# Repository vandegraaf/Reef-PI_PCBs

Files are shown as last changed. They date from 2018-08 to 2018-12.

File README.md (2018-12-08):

# Reef-PI_PCBs
Contains schematics and PCB file for use with open source Reef-PI software

2 boards are presently uploaded:
HAT (interface to Raspberry 2 or 3) with following functions:
* Can drive up to 16 external relais modules
* Can drive up to 2 12V dosing pumps
* Can use up to 2 optical ATO (water) sensors
* Can drive multiple DS18B20 temperature sensors
* Can connect to external I2C boards (not yet tested)
It requires an external 12V power supply to operate the dosing pumps
This board has been tested (except I2C, but should be ok). No changes were made to the schematics, but some improvements to power and dosing connections have been made to the PCB
The HAT documentation contains all information of which connectors and related GPIO signals to use

New PWM module added
New Reef-PI_PWM v1.0 PCB files added (no documentation yet). These files have some minor improvements over the tested v0.3, mainly to avoid a potential collission with the DS18B20 connector on the Reef-PI_HAT. No changes have been made to the schematics between v0.3 and v1.0 of the PCB.
This Reef-PI_PWM module fits on top of the Reef-PI_HAT but can of course also be connected via wiring. It must be noted that the distance between the 2.5mm PWM output connectors is very small, only very small 2.5mm connectors will fit if all 16 channels are going to be used. The documentation provides a potential candidate.

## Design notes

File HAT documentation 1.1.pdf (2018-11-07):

Rev: 1.1

Page 1 of 12

# Notes to Reef-PI HAT

### Contents

### 1. Main HAT board: | 3

### 2. Schematic: | 4

### 3. Functional overview: | 5

### 4. BOM: | 5

### 5. Connectors: | 7

5.1. 12V input: | 7

### 5.2. External relays interfaces: | 7

### 5.3. Dosing interfaces: | 8

### 5.4. ATO interface: | 9

### 5.5. Temperature sensor interface: | 10

### 5.6. Raspberry PI interface: | 11

### 5.7. I2C interface: | 11

Figure 1: Top HAT board | 3
Figure 2: Bottom HAT board | 3
Figure 3: HAT schematics | 4
Figure 4: Overview HAT functions | 5
Figure 5: Relays interface | 7
Figure 6: Intended external relays board | 8
Figure 7: Dosing interfaces | 8
Figure 8: 4 pin dosing interfaces | 9
Figure 9: Intended optical water sensor | 10
Figure 10: 3 pin DS18B20 interface | 10
Figure 11: Mounting multiple DS18B20 sensors | 10
Figure 12: Intended 3.5mm stereo jack connector | 11
Figure 13: Raspberry GPIO pin overview | 11
Table 1: Revision history | 2
Table 2: Things to do to this document | 2
Table 3: BOM with values and footprints | 6
Table 4: BOM with datasheets | 6
Table 5: BOM with potential suppliers | 7
Table 6: Top 10 connections | 7
Table 7: Bottom 10 connections | 8
Table 8: Overview GPIO ports to control dosing interfaces | 9

Page 2 of 12

Revision | Reason | Date
1.0 | Original release for HAT v1.0 | 13 Aug 2018
1.1 Update table 6 for temperature sensor (tip and ring reversed) for HAT v1.0 | (thanks to Speedstar) Reviewed and updated HAT.csv file (BOM including datasheets, potential supplier and Manufacturing Part Numbers) Added page numbers to this document Added list of items to update to this document Added revision history to this document | 7 Nov 2018

Table 1: Revision history

Planned updates to this document:

| Planned addition or update
a) Add photo’s of complete assembled Reef-PI HAT
b) Add “introduction” paragraph to describe purpose of the Reef-PI HAT
c) Add “assembly instructions” paragraph
d) Update “relays interface” paragraph: | - Which ULN2803 can be left out if only 4 or 8 relays are required - How to connect relays boards with external power (e.g. 12V)
e) Add “debugging” paragraph
f) Add list of potential “updates to the Reef-PI HAT” design
g) Update figure 11 for better description of temperature sensor cabling
Table 2: Things to do to this document

### 1. Main HAT board:

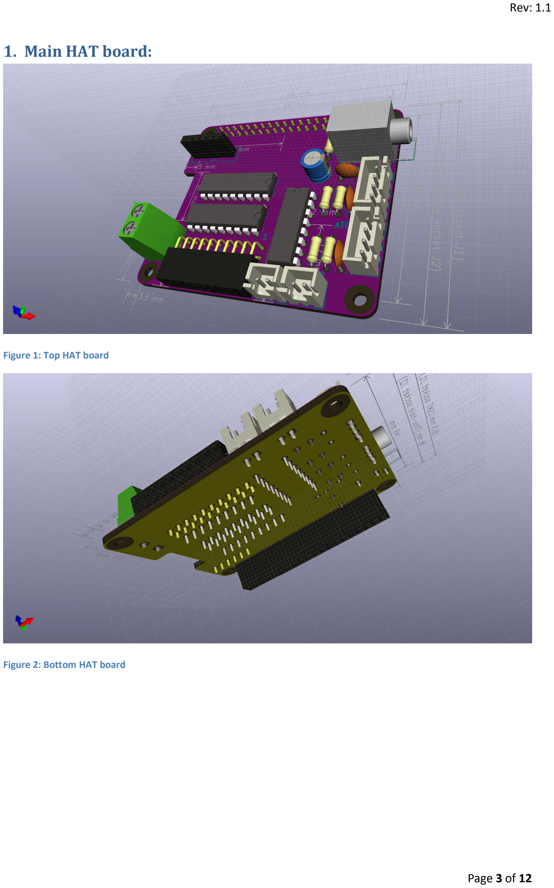
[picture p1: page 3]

Page 3 of 12

Figure 1: Top HAT board

Figure 2: Bottom HAT board

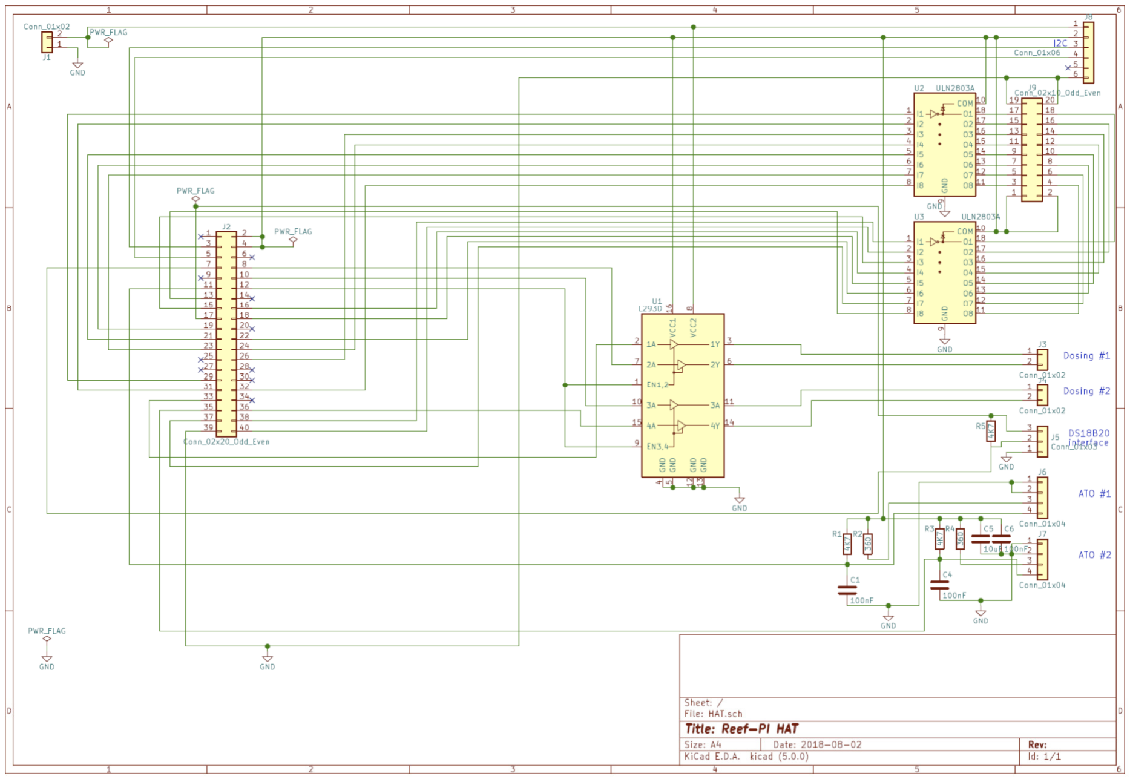
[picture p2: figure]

Page 4 of 12

### 2. Schematic:

Figure 3: HAT schematics

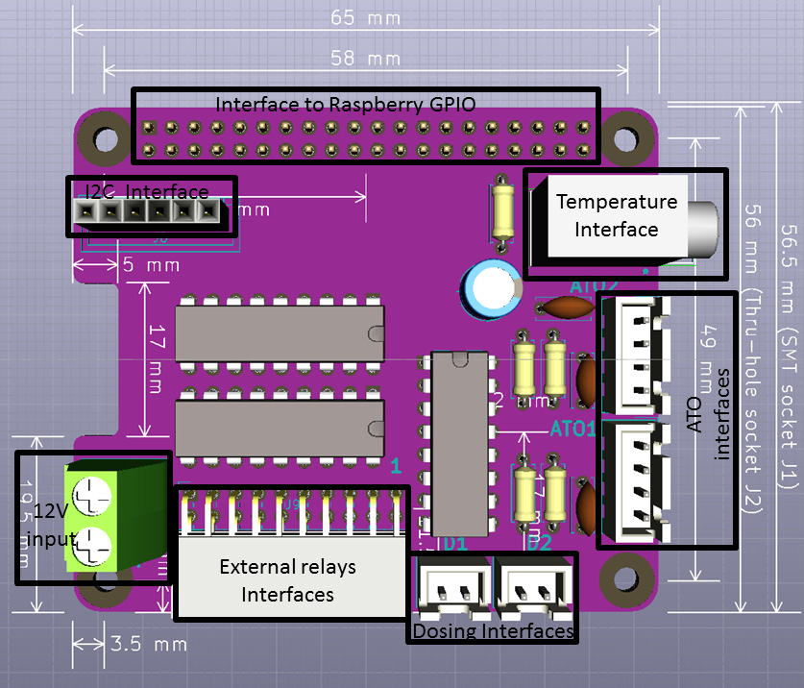
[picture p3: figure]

Page 5 of 12

### 3. Functional overview:

Figure 4: Overview HAT functions

### 4. BOM:

The proposed links are for easy finding, but most components can be found at various Internet sites at better prices such as Aliexpress, Banggood, eBay and Amazon. Purpose of this info is to provide as much as possible of information to find the required components.

The present KiCad files show D1, D2, ATO1 and ATO2 as straight connectors, you may choose to use 90 degree turned connectors for easier access in case additional Reef I2C boards (e.g. PWM module) are going to be added.

Page 6 of 12

Table 3: BOM with values and footprints

Table 4: BOM with datasheets

Title | Reef-PI HAT
Revision | 1
Date | 8/2/2018
Generated | 11/7/2018 8:25
Company
Comment 1
Comment 2
Comment 3
Comment 4
Total Parts | 21
Total Unique Parts 13
Ref | Qty | Value | Footprint
C1 C4 C6 | 3 | 100nF | Capacitors_THT:C_Disc_D6.0mm_W2.5mm_P5.00mm
C5 | 1 | 10uF | Capacitors_THT:CP_Radial_D6.3mm_P2.50mm
J1 | 1 | Conn_01x02 | Pin_Headers:Pin_Header_Straight_1x02_Pitch2.54mm
J2 | 1 | Conn_02x20_Odd_Even | Pin_Headers:Pin_Header_Straight_2x20_Pitch2.54mm
J3 J4 | 2 | Conn_01x02 | Pin_Headers:Pin_Header_Straight_1x02_Pitch2.54mm
J5 | 1 | Conn_01x03 | SJ1-3533NG:CUI_SJ1-3533NG
J6 J7 | 2 | Conn_01x04 | Pin_Headers:Pin_Header_Straight_1x04_Pitch2.54mm
J8 | 1 | Conn_01x06 | Pin_Headers:Pin_Header_Straight_1x06_Pitch2.54mm
J9 | 1 | Conn_02x10_Odd_Even | Socket_Strips:Socket_Strip_Angled_2x10_Pitch2.54mm
R1 R3 R5 | 3 | 4K7 | Resistors_THT:R_Axial_DIN0207_L6.3mm_D2.5mm_P7.62mm_Horizontal
R2 R4 | 2 | 360 | Resistors_THT:R_Axial_DIN0207_L6.3mm_D2.5mm_P7.62mm_Horizontal
U1 | 1 | L293D | Housings_DIP:DIP-16_W7.62mm
U2 U3 | 2 | ULN2803A | Housings_DIP:DIP-18_W7.62mm

BOM made with KICAD_BOM_WIZARD (https://github.com/HashDefineElectronics/KiCad_BOM_Wizard.git) Generated 11/7/2018 8:25:58 AM

Ref | Qty | Value | Datasheet
C1 C4 C6 | 3 | 100nF | https://www.mouser.com/datasheet/2/212/F3294_MMK-1101858.pdf
C5 | 1 | 10uF | https://www.mouser.com/datasheet/2/88/RSS_series-553040.pdf
J1 | 1 | Conn_01x02 | https://www.mouser.com/datasheet/2/324/ItemDetail_1715022-929342.pdf
J2 | 1 | Conn_02x20_Odd_Even
J3 J4 | 2 | Conn_01x02 | http://www.jst-mfg.com/product/pdf/eng/eXH.pdf
J5 | 1 | Conn_01x03 | https://www.cui.com/product/resource/sj1-353xng.pdf
J6 J7 | 2 | Conn_01x04 | http://www.jst-mfg.com/product/pdf/eng/eXH.pdf
J8 | 1 | Conn_01x06 | https://www.mouser.at/datasheet/2/181/M20-782-1220556.pdf
J9 | 1 | Conn_02x10_Odd_Even | https://drawings-pdf.s3.amazonaws.com/10494.pdf
R1 R3 R5 | 3 | 4K7 | https://www.mouser.at/datasheet/2/447/Yageo%20LR_MFR_2013-467719.pdf
R2 R4 | 2 | 360 | https://www.mouser.at/datasheet/2/447/Yageo%20LR_MFR_2013-467719.pdf
U1 | 1 | L293D | http://www.ti.com/lit/gpn/l293d
U2 U3 | 2 | ULN2803A | https://www.mouser.com/datasheet/2/389/uln2801a-957494.pdf

Page 7 of 12

Table 5: BOM with potential suppliers

For better readability refer to the HAT.csv file

### 5. Connectors:

5.1.12V input:
Required 12V power supply to drive the dosing motors. Plus and minus are indicated on the board.

5.2.External relays interfaces:

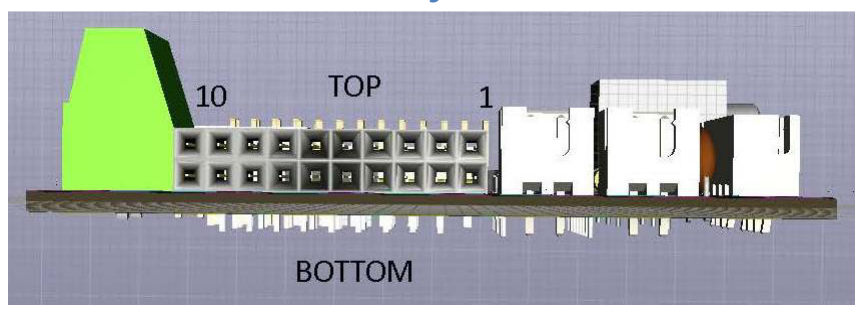
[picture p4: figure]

Figure 5: Relays interface

Top 10 pin connect relays:
Connector HAT | Relays | GPIO/Power
1 | - | GND
2 | 1 | 5
3 | 2 | 6
4 | 3 | 7
5 | 4 | 8
6 | 5 | 9
7 | 6 | 10
8 | 7 | 11
9 | 8 | 12
10 | - | 5V
Table 6: Top 10 connections

Bottom 10 pin connector relays:
Connector HAT | Relays | GPIO/Power
11 | - | GND
12 | 1 | 20
13 | 2 | 21
14 | 3 | 22
Ref | Available
C1 C4 C6 | https://www.mouser.com/ProductDetail/KEMET/MMK5104J50J01TR18L165TR18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
C5 | https://www.mouser.com/ProductDetail/Illinois-Capacitor-CDE/106RSS050M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
J1 | https://www.mouser.com/ProductDetail/Phoenix-Contact/1715022?qs=sGAEpiMZZMv8kklI404QlQ5JHVXTAtUD
J2 | https://www.mouser.at/ProductDetail/Adafruit/2222?qs=sGAEpiMZZMsMyYRRhGMFNhmPBiclXg21QVJnSoTyCdM%3d
J3 J4 | Best to buy JST XH kit at Aliexpress Banggood or eBay. Not available at Mouser (best is 90 degree turned for easier connection)
J5 | https://www.mouser.com/ProductDetail/CUI/SJ1-3533NG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
J6 J7 | Best to buy JST XH kit at Aliexpress Banggood or eBay. Not available at Mouser (best is 90 degree turned for easier connection)
J8 | https://www.mouser.at/ProductDetail/Harwin/M20-7820646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
J9 | search at Aliexpress Banggod eBay or Amazon for MPN description
R1 R3 R5 | https://www.mouser.com/ProductDetail/Yageo/CFR-25JT-52-4K7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
R2 R4 | https://www.mouser.com/ProductDetail/Yageo/MFR-25FTE52-360R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
U1 | https://www.mouser.com/ProductDetail/Texas-Instruments/L293DNE?qs=sGAEpiMZZMtYFXwiBRPs0wSafWlCmJbc
U2 U3 | https://www.mouser.com/ProductDetail/STMicroelectronics/ULN2803A?qs=sGAEpiMZZMvAvBNgSS9LqpP7ived4CP2

Page 8 of 12

15 | 4 | 23
16 | 5 | 24
17 | 6 | 25
18 | 7 | 26
19 | 8 | 27
20 | - | 5v

Table 7: Bottom 10 connections

Connector HAT: The pin positions as shown in picture Figure 5: Relays interface Relays: Usual external relays numbers when connected with 1-1 cable
GPIO: Shows under which GPIO ports the relays can be switched On/Off

Intended external relay module:

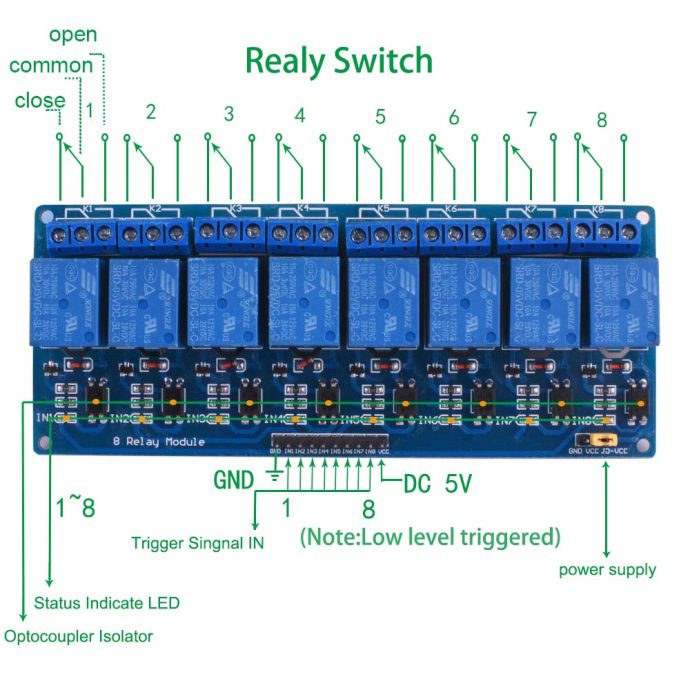
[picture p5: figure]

Figure 6: Intended external relays board

Also a smaller (4 channel) relay module can be used, but then a 10 to 6 pin adapter cable will be required. No external power supply is required. A total of 2 8 channel relays can be supported to have a total of 16 I/O interfaces.

5.3.Dosing interfaces:

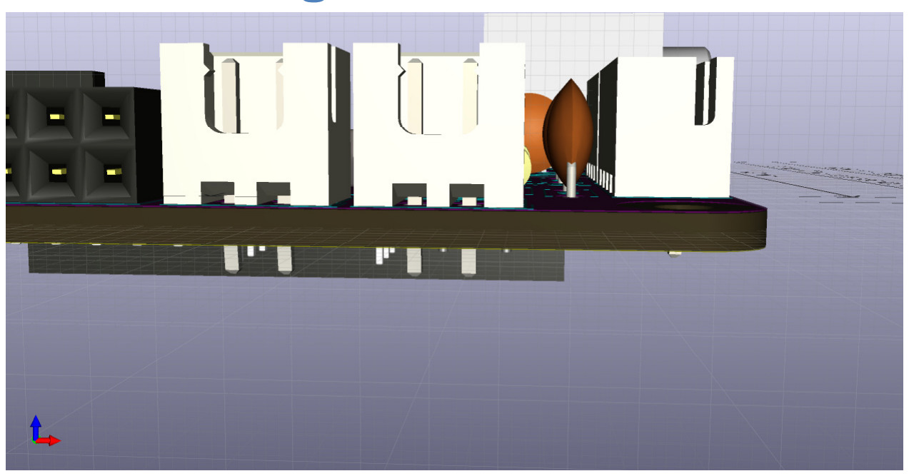
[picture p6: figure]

Figure 7: Dosing interfaces

Page 9 of 12

Dosing motors are indicated on the HAT as D1 (left) and D2 (right)

In order for the dosing motors to function, the l293D must be enabled via GPIO port 18. Connectors are JST-XH (other will work as well, but since the optical ATO sensor has a 4pin JST-XH connector, the same 2 pin type has been selected).

GPIO port | Function
13 0/12V interface to motor #1 14 0/12V interface to motor #1 15 0/12V interface to motor #2
16 0/12V interface to motor #2
18 Enable both dosing interfaces
Table 8: Overview GPIO ports to control dosing interfaces
GPIO 18 | GPIO 13 | GPIO 14 | GPIO 15 | GPIO 16 | Motor #1 | Motor #2
OFF | - | - | - | - | OFF | OFF
ON | OFF | OFF | OFF | OFF | OFF | OFF
ON | ON | OFF | - | - | Direction 1 | -
ON | ON | ON | - | - | OFF | -
ON | OFF | ON | - | - | Direction 2 | -
ON | - | - | ON | OFF | - | Direction 1
ON | - | - | ON | ON | - | OFF
ON | - | - | OFF | ON | - | Direction 2
Table 9: Overview motor directions

5.4.ATO interface:

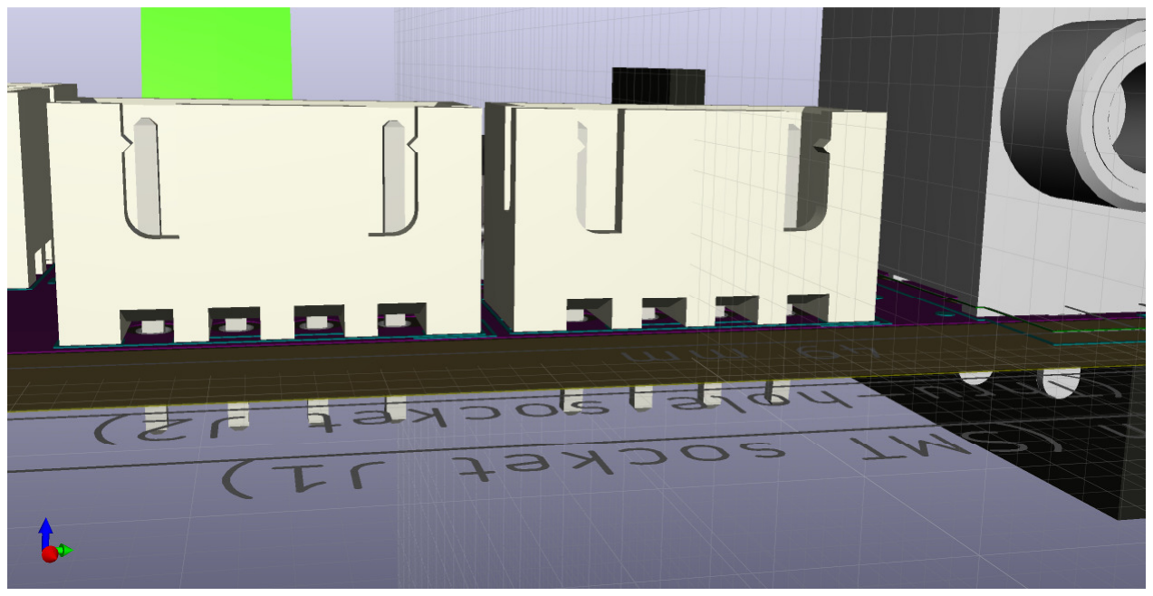
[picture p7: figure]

Figure 8: 4 pin dosing interfaces

The ATO1 (Left) and ATO2 (right are marked on the PCB. The interfaces connect to this type of probe

Page 10 of 12

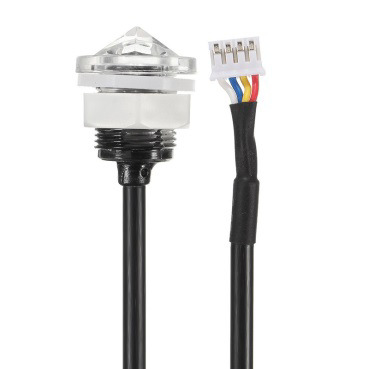
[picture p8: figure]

Figure 9: Intended optical water sensor

The values can be read out via GPIO ports 17 and 19

GPIO Port | Description
17 Read out ATO1
19 Read out ATO2
Table 10: ATO read out ports

5.5.Temperature sensor interface:

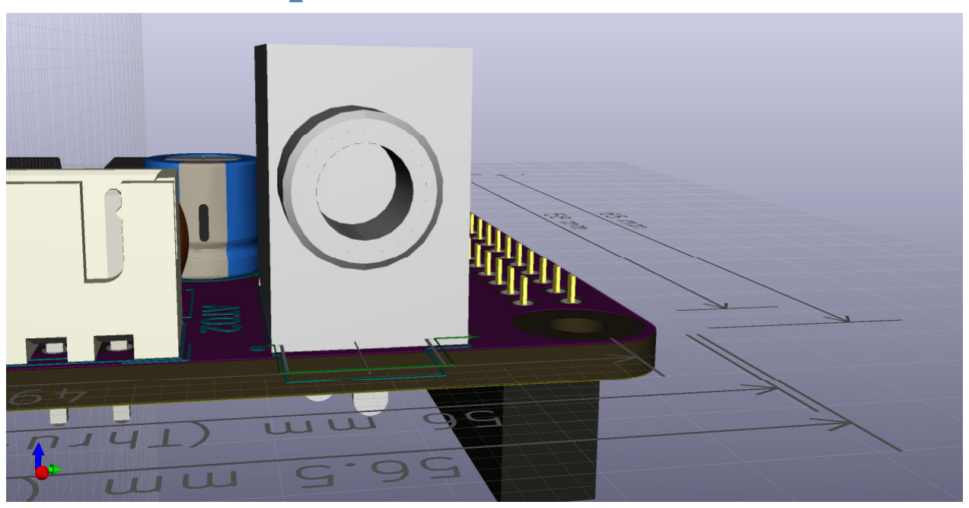
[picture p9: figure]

Figure 10: 3 pin DS18B20 interface

Multiple DS18B20 can be connected to the same interface alike this

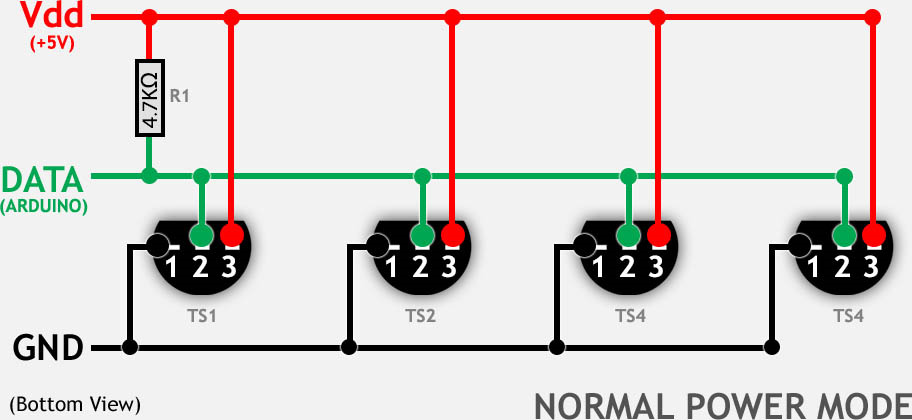
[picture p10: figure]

Figure 11: Mounting multiple DS18B20 sensors

It should be noted that the power supply is 3V3 and not 5V! The connection is done via a stereo audio plug alike this

Page 11 of 12

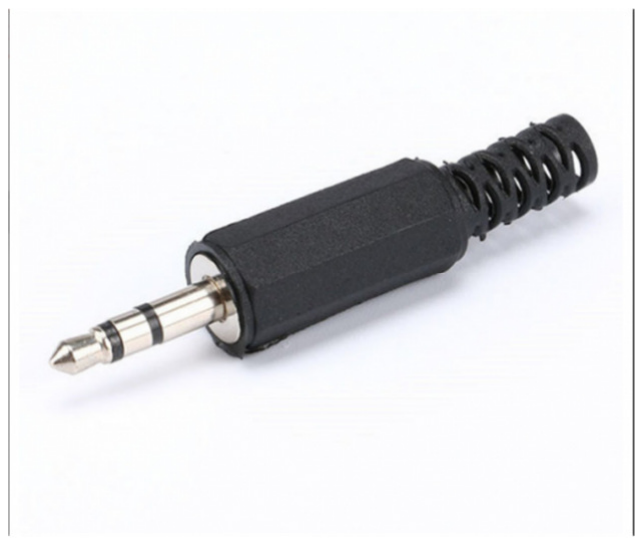
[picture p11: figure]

Figure 12: Intended 3.5mm stereo jack connector

Connections used are:

Pin | Connection
Tip (left) | Connects to GPIO 7 (DATA)
Middle | 3V3 power supply to GPIO 17 (VDD)
Right | GND to GPIO39 (GND)
Table 11: Connector pin out

5.6.Raspberry PI interface:
Female 2x20 pin strip to connect directly to the Raspberry PI 2 or 3

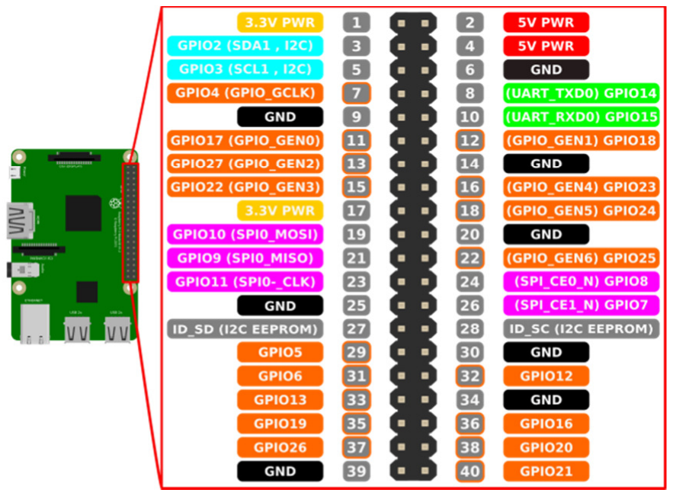
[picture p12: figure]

Figure 13: Raspberry GPIO pin overview

Only pins 27 and 28 (I2C EEPROM) are not used.

5.7.I2C interface:
Interface to external I2C boards (under development or existing). The interface provides signals
Pin | Signal
1 12V
2 5V
3 SDA

Page 12 of 12

4 SCL
5 Not connected
6 GND
Table 12: I2C interface pin out

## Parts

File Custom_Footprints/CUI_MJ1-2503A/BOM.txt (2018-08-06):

3DX_CUI_Supplier:
     CUI, Inc

3DX_CUI_Description:
     2.5 mm, Mono, Right Angle, Through Hole, Audio Jack Connector

3DX_CUI_Model Number:
     MJ1-2503A

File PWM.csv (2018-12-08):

Title,Reef-PI_PWM Module
Revision,V0.3
Date,2018-11-03
Generated,12/8/2018 12:13:19 PM
Company,
Comment 1,
Comment 2,
Comment 3,
Comment 4,
Total Parts,77
Total Unique Parts,11
Ref,Qty,Value,Footprint,Datasheet,Available,MPN,
C1 ,1,330uF,Capacitors_SMD:CP_Elec_8x10,https://www.mouser.at/datasheet/2/293/e-uwt-880115.pdf,https://www.mouser.at/ProductDetail/Nichicon/UWT1E331MNL1GS
C2 C3 ,2,100nf,Capacitors_THT:C_Disc_D6.0mm_W2.5mm_P5.00mm,https://www.mouser.at/datasheet/2/212/F3294_MMK-1101858.pdf,https://www.mouser.at/ProductDetail/kemet/mmk5104j50j01tr18l165tr18/?qs=qe%2fTxcMakihLUCH7vXErEQ==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
J1 ,1,Conn_01x06_Male,Pin_Headers:Pin_Header_Straight_1x06_Pitch2.54mm,chrome-extension://ihgdgpjankaehldoaimdlekdidkjfghe/viewer.html#https://www.mouser.at/datasheet/2/356/schmartboard_pd_920-0086-01_b-539884.pdf,https://www.mouser.at/ProductDetail/SchmartBoard/920-0086-01
J2 J3 J4 J5 J6 J7 ,6,Jumper,Jumper:SolderJumper-2_P1.3mm_Open_RoundedPad1.0x1.5mm,Not applicable,Integrated in PCB design,N/A
J8 J9 J10 J11 J12 J13 J14 J15 J16 J17 J18 J19 J20 J21 J22 J23 ,16,Audio-Jack-1,MJ1-2503A:CUI_MJ1-2503A,https://www.mouser.at/datasheet/2/670/mj1-2503a-1312398.pdf,https://www.mouser.at/ProductDetail/CUI/MJ1-2503A
Q1 Q2 Q3 Q4 Q5 Q6 Q7 Q8 Q9 Q10 Q11 Q12 Q13 Q14 Q15 Q16 ,16,BC184B,TO_SOT_Packages_THT:TO-92_Inline_Narrow_Oval,https://www.mouser.at/datasheet/2/68/bc184b-1149863.pdf,https://www.mouser.at/ProductDetail/Central-Semiconductor/BC184B
R1 R2 R3 R4 R5 R6 R7 R8 R17 R19 R21 R23 R25 R27 R29 R31 ,16,10K,Resistors_THT:R_Axial_DIN0207_L6.3mm_D2.5mm_P2.54mm_Vertical,https://www.mouser.at/datasheet/2/447/Yageo%20LR_MFR_2013-467719.pdf,https://www.mouser.com/ProductDetail/Yageo/FMP200JT-52-10K?qs=gt1LBUVyoHkKG7fWrbuf7A%3d%3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
R9 R10 R11 R12 R13 R14 R15 R16 R18 R20 R22 R24 R26 R28 R30 R32 ,16,1K,Resistors_THT:R_Axial_DIN0207_L6.3mm_D2.5mm_P2.54mm_Vertical,https://www.mouser.at/datasheet/2/447/Yageo%20LR_MFR_2013-467719.pdf,https://www.mouser.at/ProductDetail/Yageo/FMP200JR-52-1K
RN1 ,1,R_Network06,Resistors_THT:R_Array_SIP7,https://www.mouser.at/datasheet/2/54/600x-776645.pdf,https://www.mouser.at/ProductDetail/bourns/4607x-101-822lf/?qs=ehdiChDUEdUJepyEpYUqGA==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
U1 ,1,PCA9685PW,Housings_SSOP:TSSOP-28_4.4x9.7mm_Pitch0.65mm,https://www.mouser.at/datasheet/2/302/PCA9685-1127478.pdf,https://www.mouser.at/ProductDetail/NXP-Semiconductors/PCA9685PW118?qs=sGAEpiMZZMvKM5ialpXrmnWDpPMxs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
U2 ,1,uA7810,TO_SOT_Packages_THT:TO-220-3_Horizontal,https://www.mouser.at/datasheet/2/308/LM7810-1124978.pdf,https://www.mouser.at/ProductDetail/ON-Semiconductor-Fairchild/LM7810CT?qs=sGAEpiMZZMtzPgOfznR9QfzQe4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
BOM made with KICAD_BOM_WIZARD (https://github.com/HashDefineElectronics/KiCad_BOM_Wizard.git)
Generated 12/8/2018 12:13:19 PM

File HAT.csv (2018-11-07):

Title | Reef-PI HAT
Revision | 1.0
Date | 2018-08-02
Generated | 11/7/2018 8:25:58 AM
Company
Comment 1
Comment 2
Comment 3
Comment 4
Total Parts | 21
Total Unique Parts | 13
Ref | Qty | Value | Footprint | Datasheet | Available | MPN
C1 C4 C6 | 3 | 100nF | Capacitors_THT:C_Disc_D6.0mm_W2.5mm_P5.00mm | https://www.mouser.com/datasheet/2/212/F3294_MMK-1101858.pdf | https://www.mouser.com/ProductDetail/KEMET/MMK5104J50J01TR18L165TR18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 | MMK5104J50J01TR18L16.5TR18
C5 | 1 | 10uF | Capacitors_THT:CP_Radial_D6.3mm_P2.50mm | https://www.mouser.com/datasheet/2/88/RSS_series-553040.pdf | https://www.mouser.com/ProductDetail/Illinois-Capacitor-CDE/106RSS050M | 106RSS050M
J1 | 1 | Conn_01x02 | Pin_Headers:Pin_Header_Straight_1x02_Pitch2.54mm | https://www.mouser.com/datasheet/2/324/ItemDetail_1715022-929342.pdf | https://www.mouser.com/ProductDetail/Phoenix-Contact/1715022?qs=sGAEpiMZZMv8kklI404QlQ5JHVXTAtUD | 1715022
J2 | 1 | Conn_02x20_Odd_Even | Pin_Headers:Pin_Header_Straight_2x20_Pitch2.54mm |  | https://www.mouser.at/ProductDetail/Adafruit/2222?qs=sGAEpiMZZMsMyYRRhGMFNhmPBiclXg21QVJnSoTyCdM%3d | 2222
J3 J4 | 2 | Conn_01x02 | Pin_Headers:Pin_Header_Straight_1x02_Pitch2.54mm | http://www.jst-mfg.com/product/pdf/eng/eXH.pdf | Best to buy JST XH kit at Aliexpress Banggood or eBay. Not available at Mouser (best is 90 degree turned for easier connection) | http://www.jst-mfg.com/product/pdf/eng/eXH.pdf
J5 | 1 | Conn_01x03 | SJ1-3533NG:CUI_SJ1-3533NG | https://www.cui.com/product/resource/sj1-353xng.pdf | https://www.mouser.com/ProductDetail/CUI/SJ1-3533NG | SJ1-3533NG
J6 J7 | 2 | Conn_01x04 | Pin_Headers:Pin_Header_Straight_1x04_Pitch2.54mm | http://www.jst-mfg.com/product/pdf/eng/eXH.pdf | Best to buy JST XH kit at Aliexpress Banggood or eBay. Not available at Mouser (best is 90 degree turned for easier connection) | http://www.jst-mfg.com/product/pdf/eng/eXH.pdf
J8 | 1 | Conn_01x06 | Pin_Headers:Pin_Header_Straight_1x06_Pitch2.54mm | https://www.mouser.at/datasheet/2/181/M20-782-1220556.pdf | https://www.mouser.at/ProductDetail/Harwin/M20-7820646 | M20-7820646
J9 | 1 | Conn_02x10_Odd_Even | Socket_Strips:Socket_Strip_Angled_2x10_Pitch2.54mm | https://drawings-pdf.s3.amazonaws.com/10494.pdf | search at Aliexpress Banggod eBay or Amazon for MPN description | 2.54mm Pitch 2x10 Pin 20 Pin Female Double Row Right Angle Pin Header Strip
R1 R3 R5 | 3 | 4K7 | Resistors_THT:R_Axial_DIN0207_L6.3mm_D2.5mm_P7.62mm_Horizontal | https://www.mouser.at/datasheet/2/447/Yageo%20LR_MFR_2013-467719.pdf | https://www.mouser.com/ProductDetail/Yageo/CFR-25JT-52-4K7 | CFR-25JT-52-4K7
R2 R4 | 2 | 360 | Resistors_THT:R_Axial_DIN0207_L6.3mm_D2.5mm_P7.62mm_Horizontal | https://www.mouser.at/datasheet/2/447/Yageo%20LR_MFR_2013-467719.pdf | https://www.mouser.com/ProductDetail/Yageo/MFR-25FTE52-360R | MFR-25FTE52-360R
U1 | 1 | L293D | Housings_DIP:DIP-16_W7.62mm | http://www.ti.com/lit/gpn/l293d | https://www.mouser.com/ProductDetail/Texas-Instruments/L293DNE?qs=sGAEpiMZZMtYFXwiBRPs0wSafWlCmJbc | L293DNE
U2 U3 | 2 | ULN2803A | Housings_DIP:DIP-18_W7.62mm | https://www.mouser.com/datasheet/2/389/uln2801a-957494.pdf | https://www.mouser.com/ProductDetail/STMicroelectronics/ULN2803A?qs=sGAEpiMZZMvAvBNgSS9LqpP7ived4CP2 | ULN2803A
BOM made with KICAD_BOM_WIZARD (https://github.com/HashDefineElectronics/KiCad_BOM_Wizard.git)
Generated 11/7/2018 8:25:58 AM

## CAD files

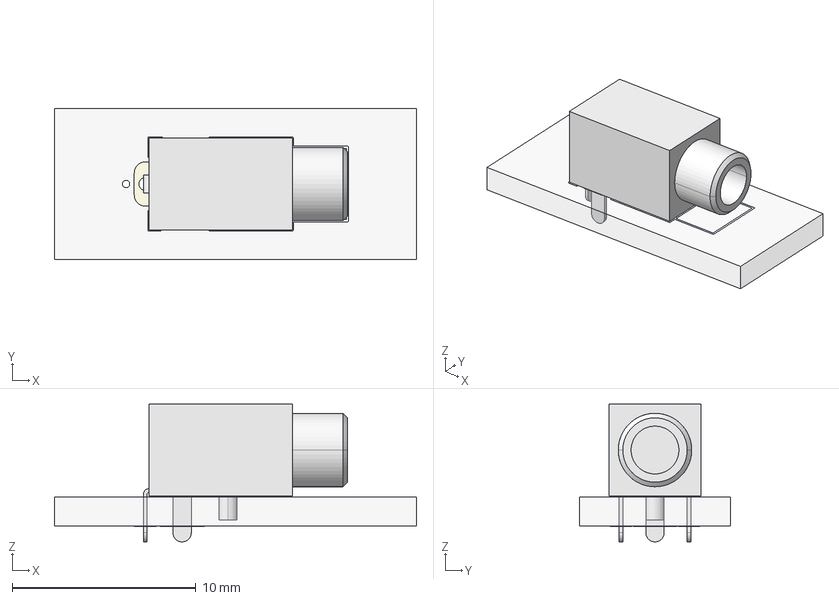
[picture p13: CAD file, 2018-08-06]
Custom_Footprints/CUI_MJ1-2503A/mj1-2503.FCStd
19.7 x 8.20 x 7.50 mm
FrontSilk
EdgeCuts
TopPads
BotPads
PTHs
Pcb
CUI_MJ1_2503A

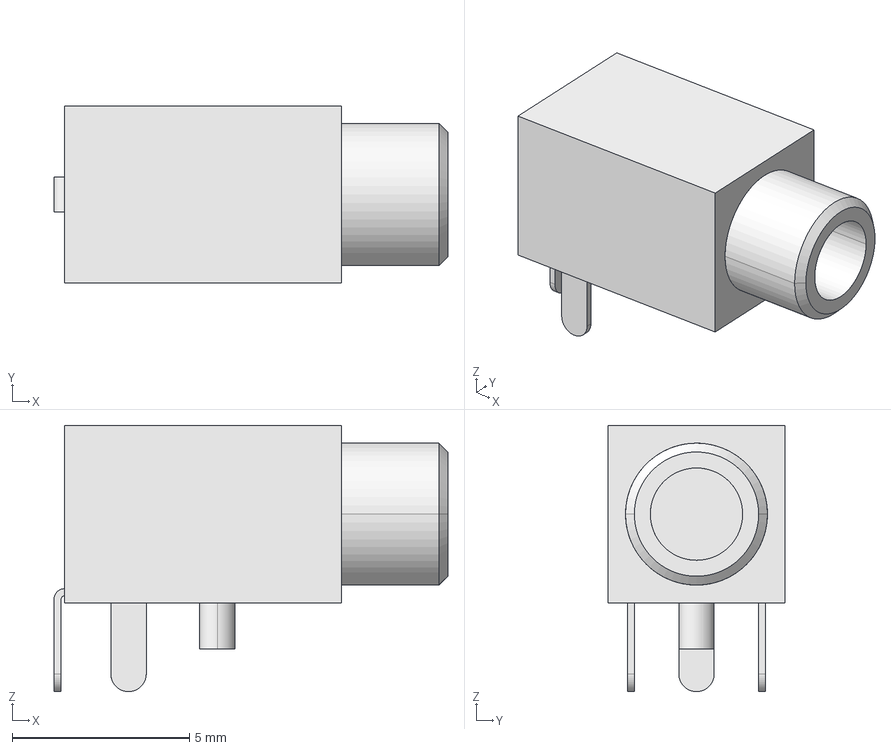
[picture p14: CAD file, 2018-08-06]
Custom_Footprints/CUI_MJ1_2503A.step
11.1 x 5.00 x 7.50 mm

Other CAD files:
Custom_Footprints/CUI_MJ1-2503A/CUI_MJ1-2503A.step
Custom_Footprints/CUI_MJ1-2503A/CUI_MJ1-2503A.igs

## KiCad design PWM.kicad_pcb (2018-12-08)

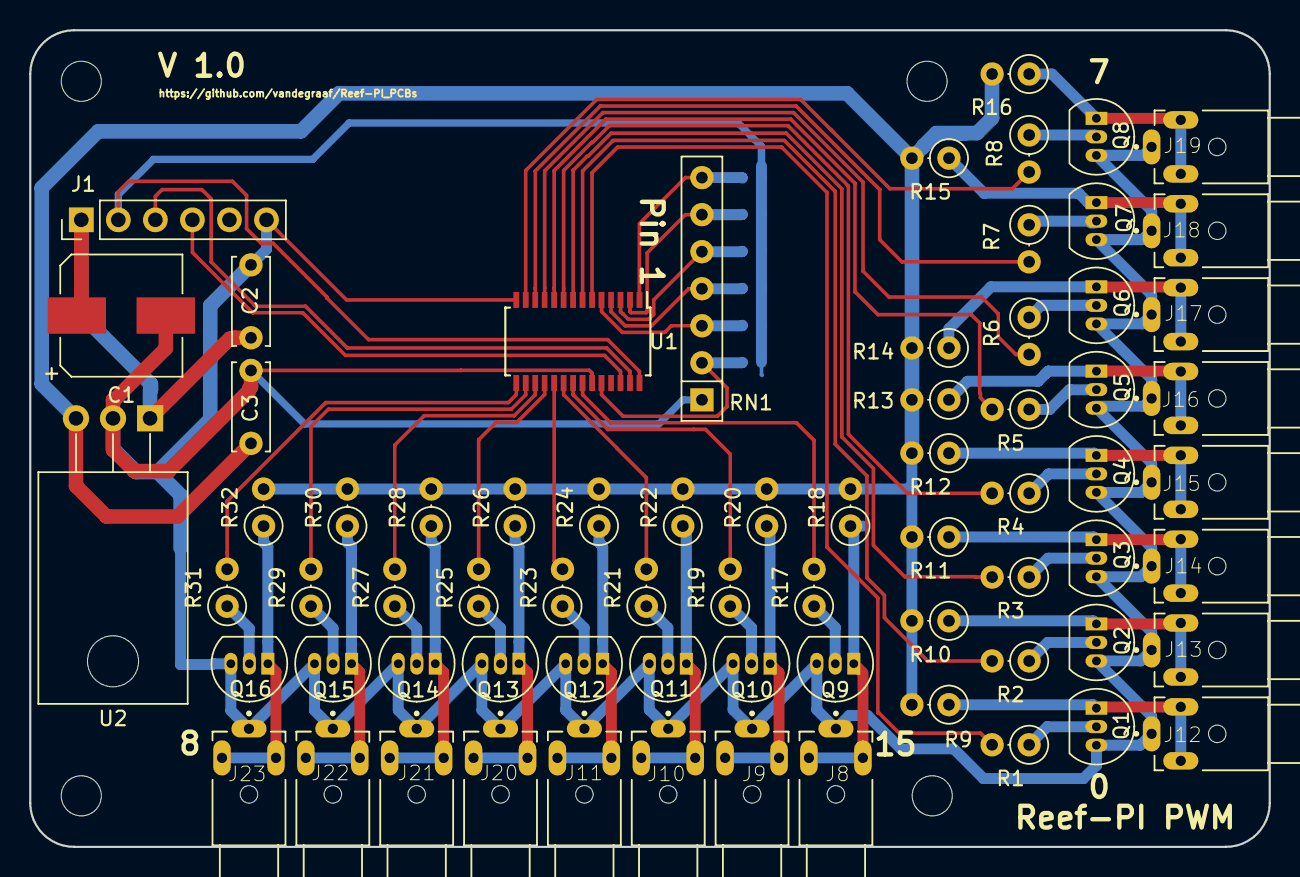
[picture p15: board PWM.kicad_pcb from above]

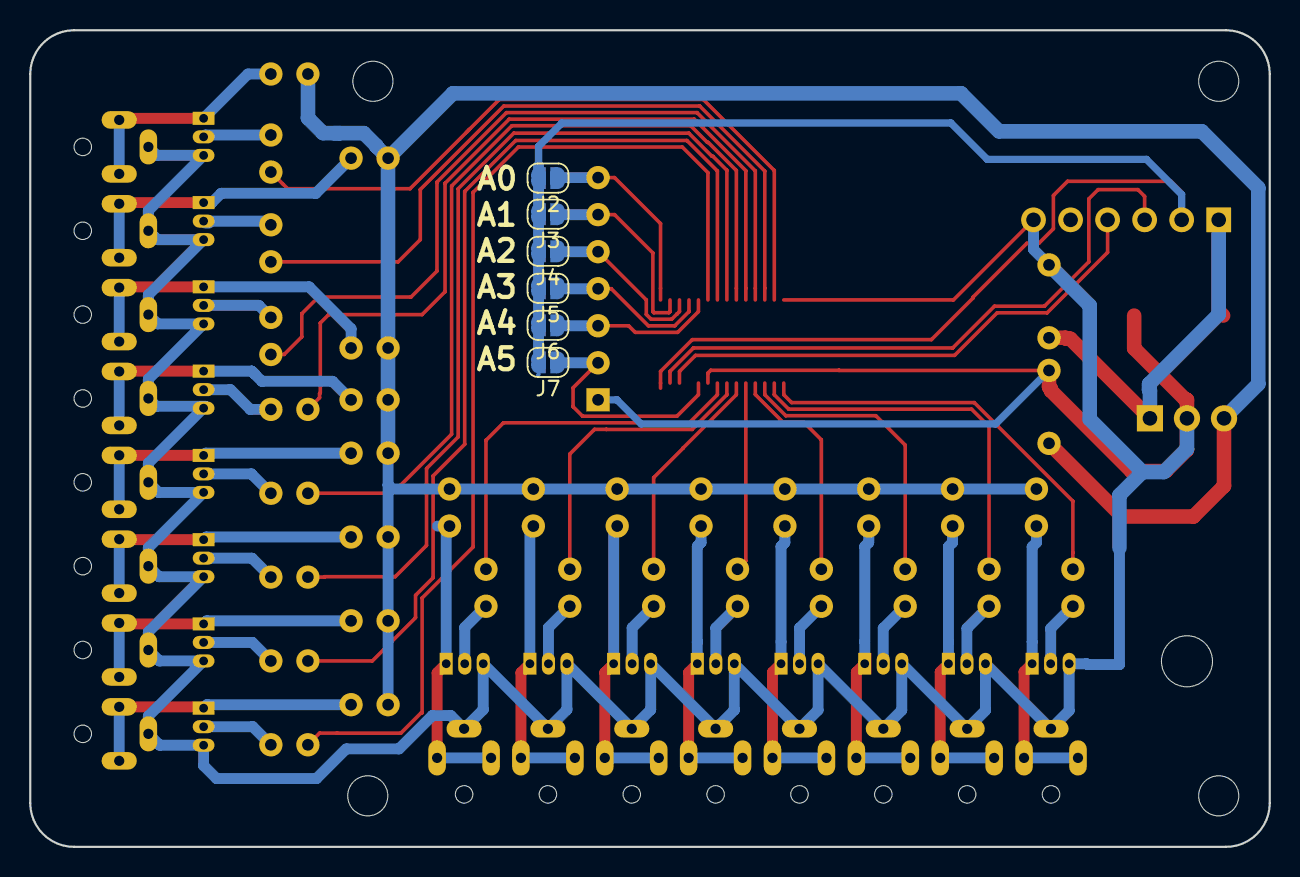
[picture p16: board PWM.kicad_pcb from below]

Board: 2 copper layers, 85.0 x 56.0 mm, 77 parts (6 on the bottom side), 60 nets.

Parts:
C1: 330uF; CP_Elec_8x10
C2, C3: 100nf; C_Disc_D6.0mm_W2.5mm_P5.00mm
J1: Conn_01x06_Male; Pin_Header_Straight_1x06_Pitch2.54mm
J2, J3, J4, J5, J6, J7: Jumper; SolderJumper-2_P1.3mm_Open_RoundedPad1.0x1.5mm
J8, J9, J10, J11, J12, J13, J14, J15, J16, J17, J18, J19, J20, J21, J22, J23: CUI_MJ1-2503A
Q1, Q2, Q3, Q4, Q5, Q6, Q7, Q8, Q9, Q10, Q11, Q12, Q13, Q14, Q15, Q16: BC184B; TO-92_Inline_Narrow_Oval
R1, R2, R3, R4, R5, R6, R7, R8, R17, R19, R21, R23, R25, R27, R29, R31: 10K; R_Axial_DIN0207_L6.3mm_D2.5mm_P2.54mm_Vertical
R9, R10, R11, R12, R13, R14, R15, R16, R18, R20, R22, R24, R26, R28, R30, R32: 1K; R_Axial_DIN0207_L6.3mm_D2.5mm_P2.54mm_Vertical
RN1: R_Network06; R_Array_SIP7
U1: PCA9685PW; TSSOP-28_4.4x9.7mm_Pitch0.65mm
U2: uA7810; TO-220-3_Horizontal

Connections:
GND: C1.2, C2.2, C3.2, J1.6, J8.1, J9.1, J10.1, J11.1, J12.1, J13.1, J14.1, J15.1, J16.1, J17.1, J18.1, J19.1, J20.1, J21.1, J22.1, J23.1, Q1.3, Q2.3, Q3.3, Q4.3, Q5.3, Q6.3, Q7.3, Q8.3, Q9.3, Q10.3, Q11.3, Q12.3, Q13.3, Q14.3, Q15.3, Q16.3, RN1.1, U1.14, U1.23, U2.2
unnamed: C1.1, C2.1, J1.1, U2.1
unnamed: C3.1, R9.2, R10.2, R11.2, R12.2, R13.2, R14.2, R15.2, R16.2, R18.2, R20.2, R22.2, R24.2, R26.2, R28.2, R30.2, R32.2, U2.3
unnamed: J1.2, J2.2, J3.2, J4.2, J5.2, J6.2, J7.2, U1.28
unnamed: J1.3, U1.27
unnamed: J1.4, U1.26
unnamed: J2.1, RN1.7, U1.1
unnamed: J3.1, RN1.6, U1.2
unnamed: J4.1, RN1.5, U1.3
unnamed: J5.1, RN1.4, U1.4
unnamed: J6.1, RN1.3, U1.5
unnamed: J7.1, RN1.2, U1.24
unnamed: J8.2, J8.3, Q9.1, R18.1
unnamed: J9.2, J9.3, Q10.1, R20.1
unnamed: J10.2, J10.3, Q11.1, R22.1
unnamed: J11.2, J11.3, Q12.1, R24.1
unnamed: J12.2, J12.3, Q1.1, R9.1
unnamed: J13.2, J13.3, Q2.1, R10.1
unnamed: J14.2, J14.3, Q3.1, R11.1
unnamed: J15.2, J15.3, Q4.1, R12.1
unnamed: J16.2, J16.3, Q5.1, R13.1
unnamed: J17.2, J17.3, Q6.1, R14.1
unnamed: J18.2, J18.3, Q7.1, R15.1
unnamed: J19.2, J19.3, Q8.1, R16.1
unnamed: J20.2, J20.3, Q13.1, R26.1
unnamed: J21.2, J21.3, Q14.1, R28.1
unnamed: J22.2, J22.3, Q15.1, R30.1
unnamed: J23.2, J23.3, Q16.1, R32.1
unnamed: Q1.2, R1.1
unnamed: Q2.2, R2.1
unnamed: Q3.2, R3.1
unnamed: Q4.2, R4.1
unnamed: Q5.2, R5.1
unnamed: Q6.2, R6.1
unnamed: Q7.2, R7.1
unnamed: Q8.2, R8.1
unnamed: Q9.2, R17.1
unnamed: Q10.2, R19.1
unnamed: Q11.2, R21.1
unnamed: Q12.2, R23.1
unnamed: Q13.2, R25.1
unnamed: Q14.2, R27.1
unnamed: Q15.2, R29.1
unnamed: Q16.2, R31.1
unnamed: R1.2, U1.6
unnamed: R2.2, U1.7
unnamed: R3.2, U1.8
unnamed: R4.2, U1.9
unnamed: R5.2, U1.10
unnamed: R6.2, U1.11
unnamed: R7.2, U1.12
unnamed: R8.2, U1.13
unnamed: R17.2, U1.22
unnamed: R19.2, U1.21
unnamed: R21.2, U1.20
unnamed: R23.2, U1.19
unnamed: R25.2, U1.18
unnamed: R27.2, U1.17
unnamed: R29.2, U1.16
unnamed: R31.2, U1.15

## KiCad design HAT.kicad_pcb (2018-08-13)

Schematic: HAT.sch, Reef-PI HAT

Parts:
C1, C6: 100nF; C_Disc_D6.0mm_W2.5mm_P5.00mm; MPN MMK5 104K50J01L4 BULK
C4: 100nF; C_Disc_D6.0mm_W2.5mm_P5.00mm; MPN MMK5104J50J01TR18L16.5TR18
C5: 10uF; CP_Radial_D6.3mm_P2.50mm; MPN 106RSS050M
J1: Conn_01x02; Pin_Header_Straight_1x02_Pitch2.54mm; MPN 651-1715022
J2: Conn_02x20_Odd_Even; Pin_Header_Straight_2x20_Pitch2.54mm; MPN 2-826925-0
J3, J4: Conn_01x02; Pin_Header_Straight_1x02_Pitch2.54mm
J5: Conn_01x03; CUI_SJ1-3533NG; MPN SJ1-3533NG
J6, J7: Conn_01x04; Pin_Header_Straight_1x04_Pitch2.54mm
J8: Conn_01x06; Pin_Header_Straight_1x06_Pitch2.54mm; MPN B6B-XH-A
J9: Conn_02x10_Odd_Even; Socket_Strip_Angled_2x10_Pitch2.54mm; MPN 2.54mm Pitch 2x10 Pin 20 Pin Female Dou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
R1, R3, R5: 4K7; R_Axial_DIN0207_L6.3mm_D2.5mm_P7.62mm_Horizontal; MPN CFR-25JT-52-4K7
R2, R4: 360; R_Axial_DIN0207_L6.3mm_D2.5mm_P7.62mm_Horizontal; MPN MFR-25FTE52-360R
U1: L293D; DIP-16_W7.62mm; MPN L293DNE
U2, U3: ULN2803A; DIP-18_W7.62mm; MPN ULN2803A

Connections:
GND: C1.2, C4.2, C5.2, C6.2, J1.1, J2.39, J5.1, J6.1, J6.2, J7.1, J7.2, J8.6, J9.19, J9.20, U1.4 (GND), U1.5 (GND), U1.12 (GND), U1.13 (GND), U2.9, U3.9
unnamed: C1.1, J2.11, J6.4, R1.2
unnamed: C4.1, J2.35, J7.4, R3.2
unnamed: C5.1, C6.1, J2.2, J2.4, J8.2, J9.1, J9.2, R1.1, R2.1, R3.1, R4.1, U1.16 (VCC1), U2.10, U3.10
unnamed: J1.2, J8.1, U1.8 (VCC2)
unnamed: J2.3, J8.3
unnamed: J2.5, J8.4
unnamed: J2.7, J5.2, R5.2
unnamed: J2.8, U1.7 (2A)
unnamed: J2.10, U1.10 (3A)
unnamed: J2.12, U1.1 (EN1,2), U1.9 (EN3,4)
unnamed: J2.13, U3.8
unnamed: J2.15, U3.3
unnamed: J2.16, U3.4
unnamed: J2.17, J5.3, R5.1
unnamed: J2.18, U3.5
unnamed: J2.19, U2.6
unnamed: J2.21, U2.5
unnamed: J2.22, U3.6
unnamed: J2.23, U2.7
unnamed: J2.24, U2.4
unnamed: J2.26, U2.3
unnamed: J2.29, U2.1
unnamed: J2.31, U2.2
unnamed: J2.32, U2.8
unnamed: J2.33, U1.2 (1A)
unnamed: J2.36, U1.15 (4A)
unnamed: J2.37, U3.7
unnamed: J2.38, U3.1
unnamed: J2.40, U3.2
unnamed: J3.1, U1.3 (1Y)
unnamed: J3.2, U1.6 (2Y)
unnamed: J4.1, U1.11 (3A)
unnamed: J4.2, U1.14 (4Y)
unnamed: J6.3, R2.2
unnamed: J7.3, R4.2
unnamed: J9.3, U2.11
unnamed: J9.4, U3.11
unnamed: J9.5, U2.12
unnamed: J9.6, U3.12
unnamed: J9.7, U2.13
unnamed: J9.8, U3.13
unnamed: J9.9, U2.14
unnamed: J9.10, U3.14
unnamed: J9.11, U2.15
unnamed: J9.12, U3.15
unnamed: J9.13, U2.16
unnamed: J9.14, U3.16
unnamed: J9.15, U2.17
unnamed: J9.16, U3.17
unnamed: J9.17, U2.18
unnamed: J9.18, U3.18

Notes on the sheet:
I2C
Dosing #1
Dosing #2
DS18B20 interface
ATO #1
ATO #2

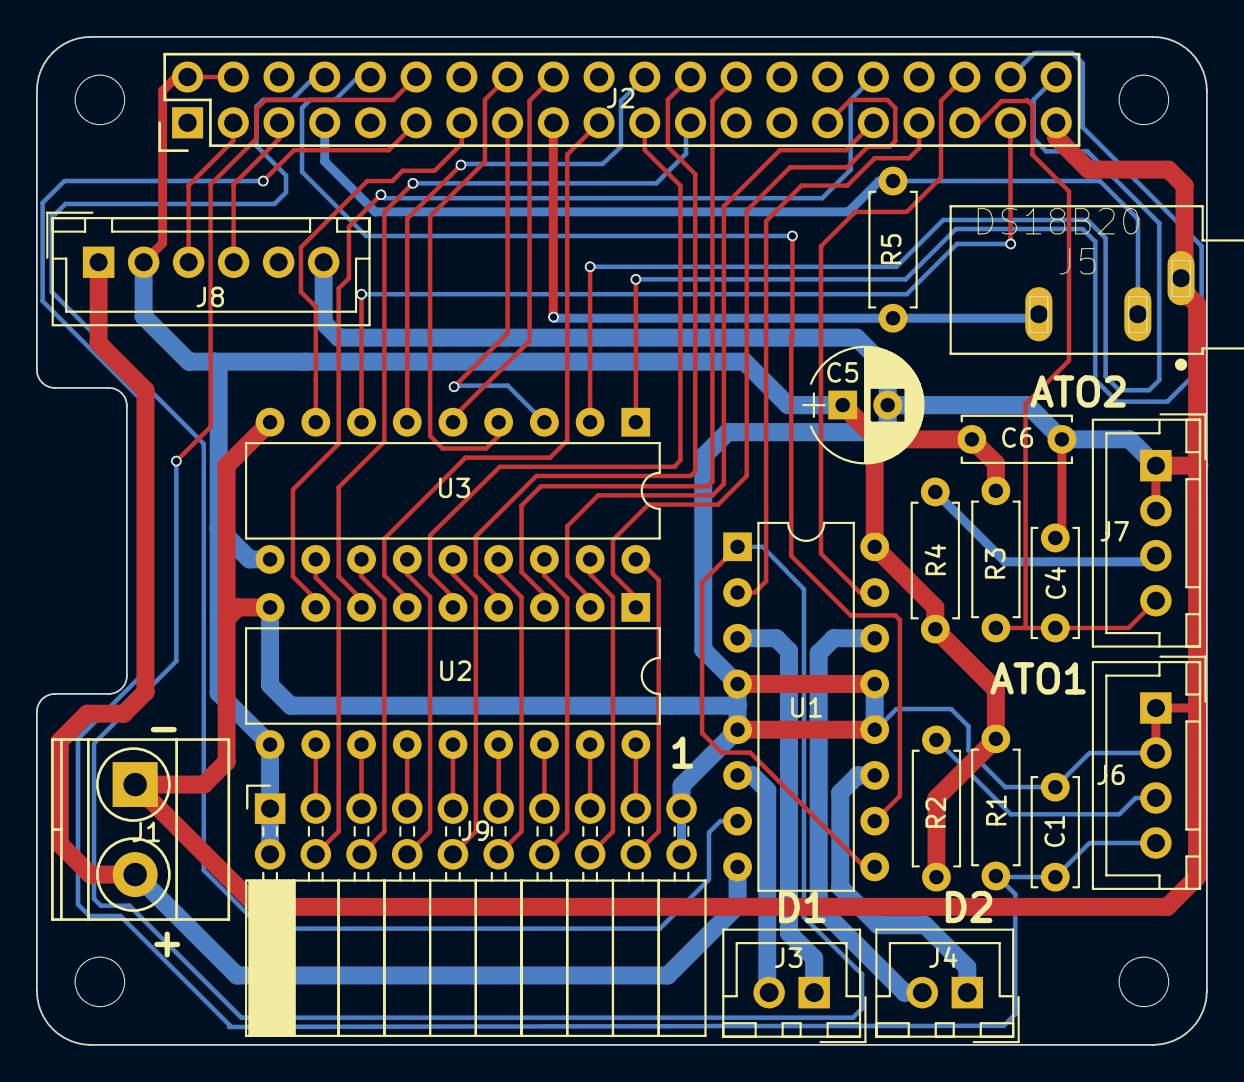
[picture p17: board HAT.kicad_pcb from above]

Board: 2 copper layers, 65.0 x 56.0 mm, 21 parts (0 on the bottom side), 52 nets.

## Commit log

2018-08-06 PWM Kicad files v0.2 added
    These schematics and PCB lay-out have not been tested yet!
    Change to v0.1 are a misalignment of the output signals and removal of all via's
    [CUI_MJ1-2503A.igs, CUI_MJ1-2503A.step, CUI_MJ1_2503A.step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]
2018-08-06 PWM Kicad files v0.2 added
    DO NOTE: these schematics and PCB's have not been tested so far
    Changes to v0.1 are a misalignment of the output channels and removal of all via's
2018-08-06 BOM and housing parameters updated
    [PWM.kicad_pcb]
2018-08-13 Reef_PI HAT files added
    This schematic for the HAT has been build and was fully functional. Nevertheless minor modifications have been made to the PCB (better grounding, larger connections to the dosing pumps), this should 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
    I've checked the boards at JLCPCB and they were completely accepted
    The HAT offers following functions:
    16 outputs to drive external relays
    2 Dosing outputs
    2 ATO inputs
    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
    [HAT.csv, HAT.kicad_pcb, HAT.sch]
2018-11-07 Add files via upload
    Reviewed and updated BOM (HAT.csv file).
    Updated HAT documentation due to a failure in the DS18B20 temperature wiring description (thanks to Speedstar for this). At the same time other parts of the documentation have been updated and/or added (see revision history).
    No changes are made to the Reef-PI HAT design (schematics/PCB)
    [HAT.csv]
2018-12-08 Reef-PI_PWM_v1.0 PCB files added
    [PWM.csv, PWM.kicad_pcb, PWM.sch]
